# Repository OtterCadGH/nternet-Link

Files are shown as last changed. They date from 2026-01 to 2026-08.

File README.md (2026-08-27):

# nternet-Link

**An open-hardware platform that turns a TI-Nspire graphing calculator into a
networked handheld terminal.** It adds Wi-Fi, an AI chat/tutor, a camera that
reads and solves problems, and onboard storage, all through a small plug-in
device.

New to the Nspire scene? The spelling "nternet" is intentional. The Nspire's name plays on "inspire", and community projects follow suit by dropping the first letter, like the Ndless jailbreak playing on "endless". nternet is "internet", Nspire style.

Over four generations the project grew from a soldered-in modification into a
clean, reproducible, plug-in platform with a proper communication protocol and
custom PCBs.

[Discord](https://discord.gg/mB2T4Wp63e)

> **Not affiliated with or endorsed by Texas Instruments.** This is an
> embedded-systems and networking experiment. It is **not** designed or
> intended for use during exams. Follow your institution's rules.

---

## Try the calculator interface in your browser

The V4 calculator UI runs as a live simulator. The on-screen calculator and a
virtual ESP32 talk over the *real* V4 wire protocol, so you can experiment with
the whole experience before building anything.

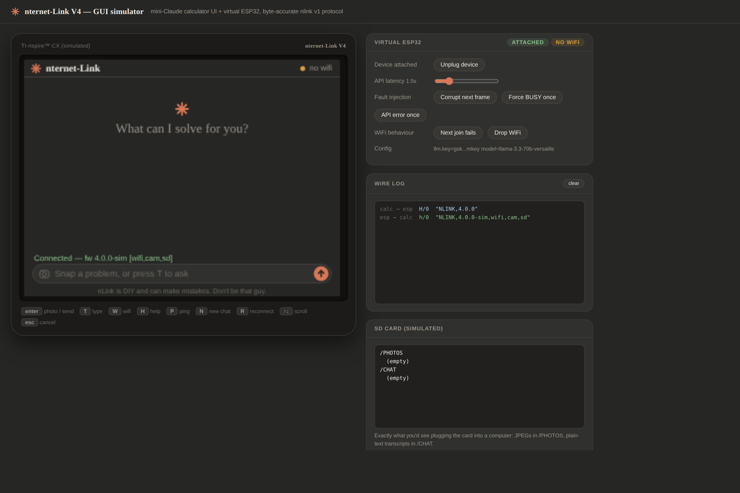
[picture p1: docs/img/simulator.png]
nternet-Link V4 GUI simulator


**[Open the live simulator](https://ottercadgh.github.io/nternet-Link/v4/tools/gui_simulator.html)**,
or download [`v4/tools/gui_simulator.html`](v4/tools/gui_simulator.html) and
open it in any browser (it runs fully offline).

---

## Which version should I look at?

**Build [V4](v4/). It is the current, recommended generation.** The others are
here as history and reference.

| | Version | What it is | Build it? |
| --- | --- | --- | --- |
| 🟢 | **[V4](v4/)** | Rewritten firmware, protocol, and UI. Two custom PCBs: a full **camera** stick and a tiny **chat-only** board. Browser simulator, automated tests. | **Yes, start here** |
| ⚪ | [V3](v3/) | First ESP32-S3 and camera platform, with a host proxy server. | Superseded |
| ⚪ | [V2](v2/) | First external USB plug-in adapter (ESP32-C3). No calculator mod. | Superseded |
| ⚪ | [V1](v1/) | The original: an ESP32 soldered *inside* the calculator. | Legacy / reference |

---

## How it works

```
 TI-Nspire  =USB=>  nternet-Link device  =Wi-Fi=>  AI provider
 (keyboard,         (ESP32 + USB bridge             (Groq / OpenAI /
  screen, Lua)       + camera + SD)                  OpenRouter / local)
```

The calculator supplies the keyboard and screen and runs a Lua app. The device
is an ESP32 that bridges USB-serial to Wi-Fi, calls an AI API, drives a camera,
and stores photos and chat logs on a microSD card. In V4 the two sides speak
**nlink v1**, a framed protocol with CRC checks and automatic retries.

---

## Repository layout

```
README.md          you are here: the project hub
docs/              shared assets (hub images)
v1/                Ti-GPT, internal mod (legacy)
   firmware/       ESP32 .ino
   calculator/     Lua app + .tns
v2/                external adapter (docs)
v3/                ESP32-S3 and camera platform
   firmware/       ESP32 .ino
   calculator/     Lua app + .tns
   server/         host proxy server
v4/                CURRENT: the full rewrite
   README.md       tutorial and build guide (start here)
   src/ include/   ESP32 firmware (C++)
   calculator/     TI-Nspire Lua client + demo
   tools/          browser GUI simulator
   docs/           protocol spec
   test/           host-side tests
   hardware/       PCB design + 4 KiCad board variants
```

Each version folder has its own README. New here? Open [`v4/`](v4/).

---

## The story

**V1 (2025)** proved the concept by soldering an ESP32 onto the calculator's
USB lines. **V2** moved all the electronics *outside* into a plug-in adapter,
with no calculator modification. **V3** jumped to the ESP32-S3 with a camera
and a host proxy. **V4** is the ground-up rewrite: a reliable checksummed
protocol, no API keys in the source (they live in the device's flash), support
for any OpenAI-compatible AI provider, a browser simulator, automated tests,
and two custom circuit boards.

## License and spirit

Open hardware and software. Modify, improve, and share. Built for learning
about USB, serial protocols, embedded networking, and hardware interfacing.

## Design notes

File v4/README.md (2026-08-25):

# nternet-Link V4

**Turn a TI-Nspire graphing calculator into a networked handheld terminal.**
It adds Wi-Fi, an AI chat/tutor, a camera that reads and solves problems, and a
microSD card, all through a tiny plug-in device. No calculator modification.

V4 is a ground-up rewrite of the firmware, the calculator software, the
communication protocol, and the hardware, with two board designs: a full
camera stick and a tiny chat-only "stealth" version.

> **Not affiliated with Texas Instruments.** This is an embedded-systems and
> networking experiment. It is **not** designed or intended for use during
> exams. Follow your school's rules. Don't be that guy.

---

## Try it first: the calculator UI runs in your browser

Before you build anything, you can play with the exact interface the
calculator runs. This simulator is the *real* thing: the on-screen
calculator and a virtual ESP32 talk to each other over the actual V4 wire
protocol, byte for byte.

nternet-Link V4 GUI simulator

### [Open the live simulator](https://ottercadgh.github.io/nternet-Link/v4/tools/gui_simulator.html)

*(That live link works once GitHub Pages is enabled. See
[Publish the demo](#publish-the-demo-optional) below. Until then, download
[`tools/gui_simulator.html`](tools/gui_simulator.html) and double-click it.
It runs fully offline in any browser.)*

### What to try in it

1. **Click the calculator screen** to give it keyboard focus.
2. Press **`W`**, pick a Wi-Fi network, type any password, press **Enter**.
   (It's simulated, so any password "connects.")
3. Press **`T`**, type a question like `derivative of x^2`, press **Enter**,
   and watch the orange spark "think," then the answer stream in.
4. Press **Enter** on its own to "take a photo." A photo card appears and a
   solved problem streams back. Check the **SD card** panel: `IMG_0001.JPG`
   just appeared, exactly as it would on the real device.
5. Now break things on purpose with the **Virtual ESP32** panel:
   - **Corrupt next frame**: watch the wire log reject a bad packet and
     recover. This is the V4 protocol's error-checking working live.
   - **Force BUSY**, **API error**, **Drop WiFi**, **Unplug device**: see
     how the UI handles each.

The **Wire log** on the right shows every message between calculator and
device, decoded. That's the whole point of V4: a reliable, checksummed link.

---

## The four generations (and where V4 fits)

| Version | What it is | Status |
| --- | --- | --- |
| V1 Ti-GPT | ESP32 soldered *inside* the calculator | Legacy / historical |
| V2 nternet-Link | External USB plug-in adapter (ESP32-C3) | Works |
| V3 | ESP32-S3 plus camera, first modular platform | Superseded by V4 |
| **V4 (this)** | Rewritten firmware, protocol, and UI, two custom PCBs | **Current** |

**What V4 fixes from V3:** a proper checksummed packet protocol (no more
garbled responses), **no API keys baked into the source** (they live in the
device's flash, set from the calculator), support for any OpenAI-compatible AI
provider, and a clean, modular codebase with automated tests.

---

## How it works (the 30-second version)

```
 TI-Nspire  =USB=>  nternet-Link device  =Wi-Fi=>  AI provider
 (keyboard,         (ESP32 + USB bridge             (Groq / OpenAI /
  screen, Lua)       + camera + SD)                  OpenRouter / local)
```

The calculator runs a Lua app (its keyboard and screen). The device is an
ESP32 that bridges USB-serial to Wi-Fi, talks to an AI API, drives a camera,
and saves photos and chats to a microSD card. They communicate over **nlink
v1**, a small framed protocol with CRC checks and automatic retries
([full spec](docs/PROTOCOL.md)).

---

## Two boards to build

| | **nlink-cam** | **nlink-lite** |
| --- | --- | --- |
| MCU | ESP32-S3-PICO-1 (SiP) | ESP32-C3-MINI-1 |
| Features | AI chat **plus camera plus microSD** | AI chat only |
| Size | about 60 x 12.5 mm stick | about 38 x 16 mm, tiny |
| Use it for | The full experience | Minimal / discreet |

Both are in [`hardware/kicad/`](hardware/kicad/) as complete, netlist-verified
KiCad projects. Two more reference designs (`nlink-proto` on the S3-MINI-1
module, `nlink-stick` bare-chip) are included as build and de-risking variants.
See [`hardware/PCB-DESIGN.md`](hardware/PCB-DESIGN.md) for the full spec and
[`hardware/kicad/CAPTURE-PLAN.md`](hardware/kicad/CAPTURE-PLAN.md) for the
board internals.

---

## Build guide

### 1. Get the hardware

Start from a dev board to try everything before committing to a custom PCB.
A **Seeed XIAO ESP32-S3 (Sense)** gives you the S3, camera, and SD in one
module. You'll also need a **CP2102/CP2102N USB-UART bridge** and a
**USB-mini plug** to reach the calculator's port. Full parts list and wiring
in [`hardware/PCB-DESIGN.md`](hardware/PCB-DESIGN.md).

### 2. Flash the firmware

The firmware uses [PlatformIO](https://platformio.org/) (free VS Code
extension). Clone this folder, open it, and build the target for your board:

```bash
pio run -e xiao-s3    -t upload    # XIAO ESP32-S3 dev board (camera + SD)
pio run -e nlink-cam  -t upload    # custom camera PCB (ESP32-S3-PICO-1)
pio run -e nlink-lite -t upload    # custom chat-only PCB (ESP32-C3-MINI-1)
```

No secrets go in the code. You'll set your Wi-Fi and AI key **from the
calculator** in the next step.

### 3. Load the calculator app

Copy the Lua app onto your calculator with the free **TI-Nspire Student
Software** (or TiLP). The client library is
[`calculator/nlink.lua`](calculator/nlink.lua) and a ready-to-run app is
[`calculator/demo_app.lua`](calculator/demo_app.lua). Build them into a
`.tns` file and send it to the calculator.

### 4. First run

1. Plug the device into the calculator, open the app.
2. Get a free AI key (for example from [Groq](https://console.groq.com/keys)).
3. On the calculator, set it once. It's saved to the device's flash:
   ```
   CFG SET llm.key   YOUR_KEY_HERE
   CFG SET llm.base  https://api.groq.com/openai/v1
   ```
4. Press **`W`** to pick your Wi-Fi and enter the password.
5. Press **`T`** to ask a question, or **Enter** to snap a photo of a
   problem. Answers save to the SD card automatically.

Everything you'll see on screen is exactly what the
[browser simulator](#try-it-first-the-calculator-ui-runs-in-your-browser)
above shows.

---

## Repository layout

```
platformio.ini        firmware build targets
include/  src/         ESP32 firmware (C++): protocol, provisioning,
                       AI client, camera, SD storage
calculator/            TI-Nspire Lua client library + demo app
tools/gui_simulator.html   the browser demo above
docs/PROTOCOL.md       nlink v1 wire-protocol spec
test/                  host-side protocol tests (run on a PC)
hardware/              PCB design docs + 4 KiCad board variants
PROJECT-STATUS.md      current status and next steps
```

---

## Publish the demo (optional)

To make the browser simulator open from a link (so people can try it without
downloading), turn on **GitHub Pages**:

1. Repo **Settings**, then **Pages**.
2. **Build and deployment**, **Source: Deploy from a branch**.
3. Pick the branch this folder lives on and **/ (root)**, then **Save**.
4. After a minute, your simulator is live at:
   `https://ottercadgh.github.io/nternet-Link/v4/tools/gui_simulator.html`

Then the **Open the live simulator** button near the top of this page just
works.

---

## Status and roadmap

See [`PROJECT-STATUS.md`](PROJECT-STATUS.md). Short version: firmware,
protocol, simulator, and all four board schematics are done and verified.
Next up is finishing the custom-PCB layouts, porting the new UI onto the
calculator, and a first hardware bring-up.

## License and spirit

Open hardware and software. Modify, improve, and share. Built for learning
about USB, serial protocols, embedded networking, and hardware interfacing.

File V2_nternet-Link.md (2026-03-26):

# nternet-Link

### Open Source Wireless Link Adapter for TI-Nspire CX & CX II Calculators

The **nternet-Link** is an open source hardware and software alternative to the TI-Navigator wireless adapter.

It allows a TI-Nspire CX or CX II calculator to communicate with an external microcontroller over the calculator USB mini port.
This implementation uses a Seeed Studio XIAO ESP32C3 to act as a serial bridge and WiFi client, enabling data transfer, network communication, and internet connectivity for the calculator.

The project began as a proof of concept serial link and evolved into a system capable of making network requests, including a demonstration application that connects the calculator to ChatGPT through a Lua interface.

Demo: https://youtube.com/shorts/zKWZ0URra5Q?si=NUPr6w3lMf3OUgO9
---
3d Files:
https://www.thingiverse.com/thing:7322781
https://www.thingiverse.com/thing:7279226

## What It Does

The device plugs into the calculator USB mini port and creates a USB serial connection.
The ESP32C3 interprets data coming from the calculator and can:

• exchange strings and files

• act as a wireless communication bridge

• connect the calculator to the internet

• send and receive API requests

• run a ChatGPT style messaging interface on the calculator

• Run any App w/ and w/o internet capabilities

• Store Data

No modification to the calculator hardware is required.

---

## Bill of Materials

Gather the following components before beginning construction:

* Seeed Studio XIAO ESP32C3
* CP2102 USB to UART bridge module
* 90° right angle slim USB Mini male connector
* 5.6 mm toggle switch (optional)
* hookup wire (28 to 32 AWG recommended)
* soldering iron and solder
* hot glue
* 3D printed enclosure (provided in /hardware)



---

## Step 1 — Prepare the CP2102



The CP2102 board must be stripped down.

Remove:
• the USB connector
• the dupont header pins

After removal, solder wires directly to the pads:

### USB Side

| Signal | Wire Color |
| --- | --- |
| VBUS | Red |
| GND | Black |
| D+ | Green |
| D− | White |

### UART Side

| Signal | Wire Color |
| --- | --- |
| 5V | Red |
| GND | Black |
| TXD | Blue |
| RXD | Yellow |

---

## Step 2 — Attach the USB Mini Connector

Solder the USB Mini connector to the USB pads of the CP2102:

Match the signals exactly:

D+ → D+
D− → D−
VBUS → VBUS
GND → GND

This connector plugs directly into the calculator.

---

## Step 3 — Connect to the ESP32C3

Wire the CP2102 UART pins to the XIAO ESP32C3:

| CP2102 | ESP32C3 |
| --- | --- |
| TXD | RX |
| RXD | TX |
| 5V | VIN |
| GND | GND |

Important:

* TX and RX are crossed (TX → RX and RX → TX)
* Grounds must be common across all devices

Optional:
You may install the toggle switch inline with the 5V line coming from the USB Mini connector to act as a power switch.



---

## Step 4 — Install Into the Case



Place the full assembly into the provided 3D printed enclosure.

Ensure:
• the USB Mini connector aligns with the opening
• the ESP32C3 USB-C port remains accessible

---

## Step 5 — Final Assembly



Insert the toggle switch into the rear sleeve.

Then secure the electronics using hot glue:

Important:
Do NOT cover the ESP32C3.
The board must be able to pivot upward so code can be uploaded over USB-C.

The enclosure is designed so the ESP32C3 can hinge outward for programming.



---
## Step 5 — Final Assembly
Insert Nternet-Link Into calculator!



Watch the Demo Here:

https://youtube.com/shorts/zKWZ0URra5Q?si=NUPr6w3lMf3OUgO9

---

## Demo Applications

### Serial Echo Demo

A simple Lua program running on the calculator sends a string to the ESP32C3.

The ESP32C3 immediately returns the same string.

This verifies:
• USB communication
• UART communication
• calculator software communication

---

### ChatGPT Demo

A second demonstration expands the concept.

The calculator Lua application:
• accepts user text input
• sends the string to the ESP32C3

The ESP32C3:
• connects to WiFi
• performs a ChatGPT API request
• returns the response

The calculator then renders a chat style interface directly on the screen.

The result is a functional conversational interface entirely running from a graphing calculator.

---

## Software

Calculator software is written in Lua using the TI-Nspire Lua API.

ESP32 firmware is written in Arduino framework for ESP32C3.

Both are provided in the `/software` directory.

---

## Open Source

All hardware, firmware, and calculator software are released open source.

You are encouraged to modify, improve, and redistribute this project.

---

## Disclaimer

This project is not affiliated with or endorsed by Texas Instruments.

Use at your own risk. Improper wiring may damage your calculator.

---
## Next Version (In Development)

A second generation of the nternet Link is already functional and currently being documented.

The new revision replaces the XIAO ESP32C3 with the **Seeed Studio XIAO ESP32S3**.
This upgrade was chosen because the ESP32S3 supports native USB and expansion boards, which significantly increases the capabilities of the device.

The ESP32S3 version can host Seeed Studio expansion modules including:

• Camera module (live image capture experiments)
• LoRa radio module
• Meshtastic compatible mesh networking communication

This opens the possibility of calculator to calculator wireless messaging over long distances without WiFi infrastructure.

The hardware is complete and operational.
Documentation is being prepared in video format showing assembly and operation.

I am currently collaborating with another developer who is leading major improvements to the software architecture while I focus on hardware design, electrical interfacing, and integration with the TI Nspire Lua environment.

The next revision will include:
• improved communication protocol
• cleaner serial handling
• easier firmware installation
• expanded Lua user interface
• support for additional peripherals

Source code and instructions for the ESP32S3 version will be released in this repository once the software layer is finalized.

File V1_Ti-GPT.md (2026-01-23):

# Ti-GPT (V1) by OtterCad

## Project Status Update

This repository documents the original Ti-GPT V1 implementation. While this project originally started as a YouTube video walkthrough, development has since taken a different direction and expanded beyond the scope of that initial video.

I am currently working on a clean V2 redesign and will be publishing it in a **new dedicated repository** once it is ready. V2 focuses on improved hardware integration, cleaner power and signal routing, and a more refined software experience.

This repository remains available as a reference for the original concept, hardware exploration, and early implementation details.

## About This Repository

**This Repository is a how-to guide associated with a YouTube video project to enable a Ti-Nspire CX (and others) with Chat-GPT utilizing an ESP32C3 and native .tns app.**

- Link to Video: LINK  
- Link for 3D printable Replacement Ti-nspire cx series slide cover: [LINK](https://www.thingiverse.com/thing:7279226)

## TI-Nspire CX Modification Guide

### Preparation and Disassembly

#### Determine Calculator Model

- There is some room for confusion here; I refer to two generations of the CX: the CX Gen 1 and CX Gen 2. Note that the CX Gen 2 is not the CX II. For more clarification, see images below.
- The first generation of the CX, including the CX and CX CAS, had issues with driver compatibility and featured a larger TiHub chip and larger battery area took up significant internal space.
- The CX CAS Gen 2, CX II, CX II CAS, CX II-T, and CX II-T CAS, is based on the newest TI chipset with a large motherboard and an integrated TiHub chip, offering minimal internal space.
- The CX Gen 2 is the best model for this project because it is based on the early chipset with the updated smaller battery and smaller TiHub chip.
- Note: The CX CAS Gen 2, CX II, CX II CAS, CX II-T, and CX II-T CAS are capable of undergoing this modification, but the extra 1.2mm of space in the CX Gen 1 is crucial for my needs.
- The CX Gen 2 can be distinguished from other variants by its white sides, full white back, smaller battery hatch, and navy blue front. The CX Gen 2 has white sides but a navy back and a larger square battery cover.
- More details on the internal discrepancies and visuals can be found in the video and photos below.




#### Open the Battery Housing

- Use a small Phillips screwdriver to remove the battery housing cover.
- Take out the panel and the battery to expose hidden safety screws.



#### Remove Hidden Screws

- With a one-millimeter flathead screwdriver, remove the safety screws hidden under the battery cover.
- Check under the top rubber feet for additional hidden screws. Ignore the lower feet, as there are no screws there.




#### Remove Torx Screws

- At the bottom of the calculator, remove the Torx T-6 screws.
- Keep all small parts in a safe place. Note that the CAS, CX II, and CX II CAS models have extra screws under the front fascia.



#### Wedge Off the Rear Housing

- Use guitar picks or similar pry tools to gently separate the rear housing from the body, working your way around the sides until the back pops off.



#### Prepare the Motherboard

- Cover the lower motherboard face with vinyl or electrical tape to prevent any interference with the piggyback.



### Micro USB Port and Wiring

#### Address Micro USB Port

- Note that Texas Instruments reversed the pinout on the CX II; the labels are upside down. Be very careful when soldering to these pins.




#### Solder and Install Piggyback, Switches, and Connector

- Refer to the provided wiring diagram to install two switches, one for grounding the ID pin to enable host mode and the other as the main power switch for the piggyback.
- Add optional a magnetic connector to facilitate easy assembly and disassembly.
- Note pinout lables are reversed for the CX II
- Note between ESP32 and CP2102 RX -> TXD, TX -> RXD in UART communication protocol but between Ti-nspire motherboard and CP2102 D+ -> D+, and D- -> D- in USB communication protocol.



#### Adjust Internal Space

- Use necessary tools to free up internal space as needed of the calculator to accommodate the piggyback and switches.
- Optionally add USB access to the ESP for debugging purposes while it's still in the case. Heres an example of mine.

### Software Installation and Configuration

#### Download and Install Software

- Download the TI-nspire CAS student software free trial and install it.
- Use this software to upload the .tns file from the provided GitHub link to your calculator.

https://education.ti.com/fr/software/details/en/B4F6E4EE05B94D75AAB4DFE24B2720AE/ti-nspirecxcas_pc_trial

#### Setup API and Arduino

- Follow the guide by Anders Jensen to create your ChatGPT API secret key. (GUIDE LINK)
- Download and install the Arduino IDE and the necessary drivers for your ESP model.
- Edit the .INO file from this repository to include your API secret key and Hotspot or Wi-Fi details.
- Note for iphones enable Maximise Compatibility to allow your esp to connect in hotspot settings.



### Final Assembly and Testing

#### Assemble and Check Clearances

- Once all components are installed, close up the calculator by pressing firmly on the sides.
- Ensure there is enough clearance for all components.

#### Power Up and Configure

- Boot up the calculator, go to the Home Screen, enable Host mode via the first switch, and then power the piggyback bia the second switch.

#### Open and Run Ti-GPT File

- Open the Ti-GPT file in the calculator's document folder.
- Ensure the ESP has successfully connected to your hotspot.

#### Testing and Usage

- Type into the textbox and hit enter.
- For short responses, they should appear immediately.
- For longer responses, you may need to hit enter again after a few seconds.

#### Troubleshooting

- If you encounter errors, hit CTRL + W to quit the program.
- Try power cycling your piggyback and checking your wiring for any issues.
- ALWAYS disconnect power and host/ID pin when not in use.
- Esp can get pretty hot in there under load or if on/idle too long.
- Please watch the step by step on Youtube and leave a comment if you are facing issues and I will do my best to respond.

### Disclaimer

I want to make it clear that this project is created for educational purposes and technological demonstration only. I do not condone academic dishonesty or the use of this project for cheating in any form.

The tools and methods demonstrated in this project should be used responsibly and ethically. Misuse of this technology for bypassing academic regulations or dishonest practices is strictly against the principles this project upholds.

Additionally, I do not endorse or support the use of my project by others for financial gain by others. This project is open-sourced to foster innovation and learning within the community, not for commercial exploitation.

Any reproduction or use of the project's content for profit without explicit permission is strictly prohibited. Please respect the spirit of collaboration and learning that this project is built upon.

### Refrences

- ChromaLock YouTube, GitHub  
  https://www.youtube.com/@ChromaLock

- ProfessorBoots YouTube, GitHub  
  https://github.com/ProfBoots/ChatGPT-On-Arduino

- CVSoft Cemetech, GitHub  
  https://github.com/CVSoft/nspire-usb-uart-shenanigans

- AndersJensen YouTube  
  https://www.youtube.com/watch?v=OB99E7Y1cMA&ab_channel=AndersJensen

- ti-nspire YouTube  
  https://www.youtube.com/@ti-nspire301

- CSab6482 Reddit  
  https://www.reddit.com/r/UsbCHardware/comments/y2dbkf/tinspire_cx_ii_cas_usbc_mod_v2/

### Thank You

Thank you so much for engaging with my project. While this repository captures the original implementation, the project is actively evolving and V2 will be released in a separate repository with a cleaner and more refined approach.

I appreciate all the feedback, curiosity, and experimentation this project has generated. Thank you for being part of it.

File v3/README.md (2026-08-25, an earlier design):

> **nternet-Link · Version 3** — [← All versions](../README.md) · [V1](../v1/) · [V2](../v2/) · [V4](../v4/)
>
> First ESP32-S3 + camera platform. Superseded by V4 (rewritten protocol, firmware, and hardware). Code here includes the calculator app, ESP32 firmware, and a host `server/` proxy.

---

# nternet-Link V3

### Development Preview

nternet-Link V3 is the current generation of the project and remains under active development.

This version moves beyond a simple wireless adapter and turns the TI-Nspire calculator into a modular embedded terminal capable of interacting with external hardware and modern network services.

The system now uses the **Seeed Studio XIAO ESP32S3** platform and supports expansion peripherals instead of a fixed configuration.

---

## Development Update

The V3 demo programs have now been uploaded in the `/v3` folder of this repository.

These demos show working communication between the calculator Lua interface and the ESP32S3 hardware.
A full demonstration video showing the hardware, installation process, and real usage is currently being recorded and will be added to the repository soon.

---

## What It Enables

Working demonstrators currently include:

• calculator text interface to network services
• API communication through the ESP32S3
• image capture experiments
• long range wireless messaging experiments

The calculator provides the display and input while the ESP32S3 handles communication, processing, and peripherals.

---

## Expansion Direction

The platform is being designed to support attachable modules such as:

• camera input hardware
• LoRa radio communication
• Meshtastic style messaging networks

This allows calculator to calculator communication and off grid messaging without WiFi infrastructure, as well as interaction with remote services.

---

## Project Status

The hardware platform is operational and multiple prototypes are working.

I am currently collaborating with another developer who is focusing on the software architecture and communication protocol while I continue hardware integration and Lua interface development.

Current goals before full release:

• stabilize the firmware
• simplify installation
• improve reliability
• document operation clearly

Once the system is polished and reproducible, full documentation and source release will be published here along with a complete build and demonstration video.

---

## Purpose

This project explores extending legacy educational hardware using modern embedded systems and networking.

The calculator acts as a portable human interface while the external device provides connectivity and processing.

---

## Academic Use

This project is provided for learning and experimentation only and is not intended for use in examinations or to bypass institutional policies. Users are responsible for following the rules of their school or testing environment.

---

## Disclaimer

This project is not affiliated with or endorsed by Texas Instruments.

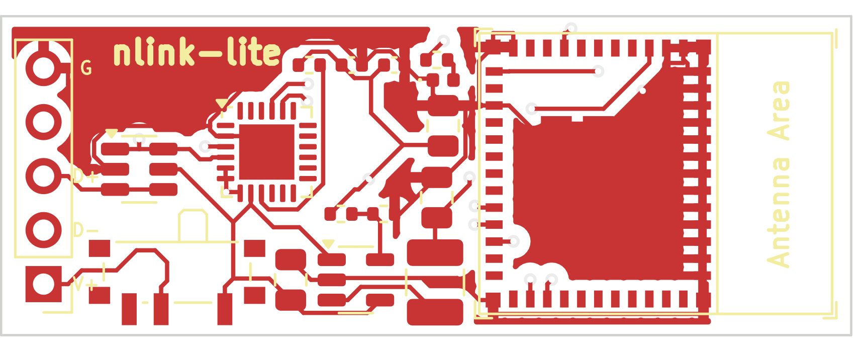
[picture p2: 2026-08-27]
v4/hardware/kicad/nlink-lite/lite_front.png

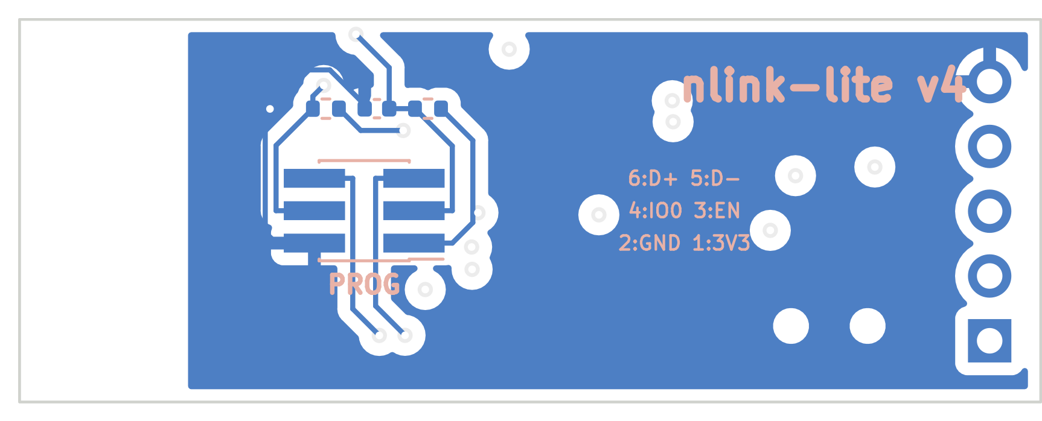
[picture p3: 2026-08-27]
v4/hardware/kicad/nlink-lite/lite_back.png

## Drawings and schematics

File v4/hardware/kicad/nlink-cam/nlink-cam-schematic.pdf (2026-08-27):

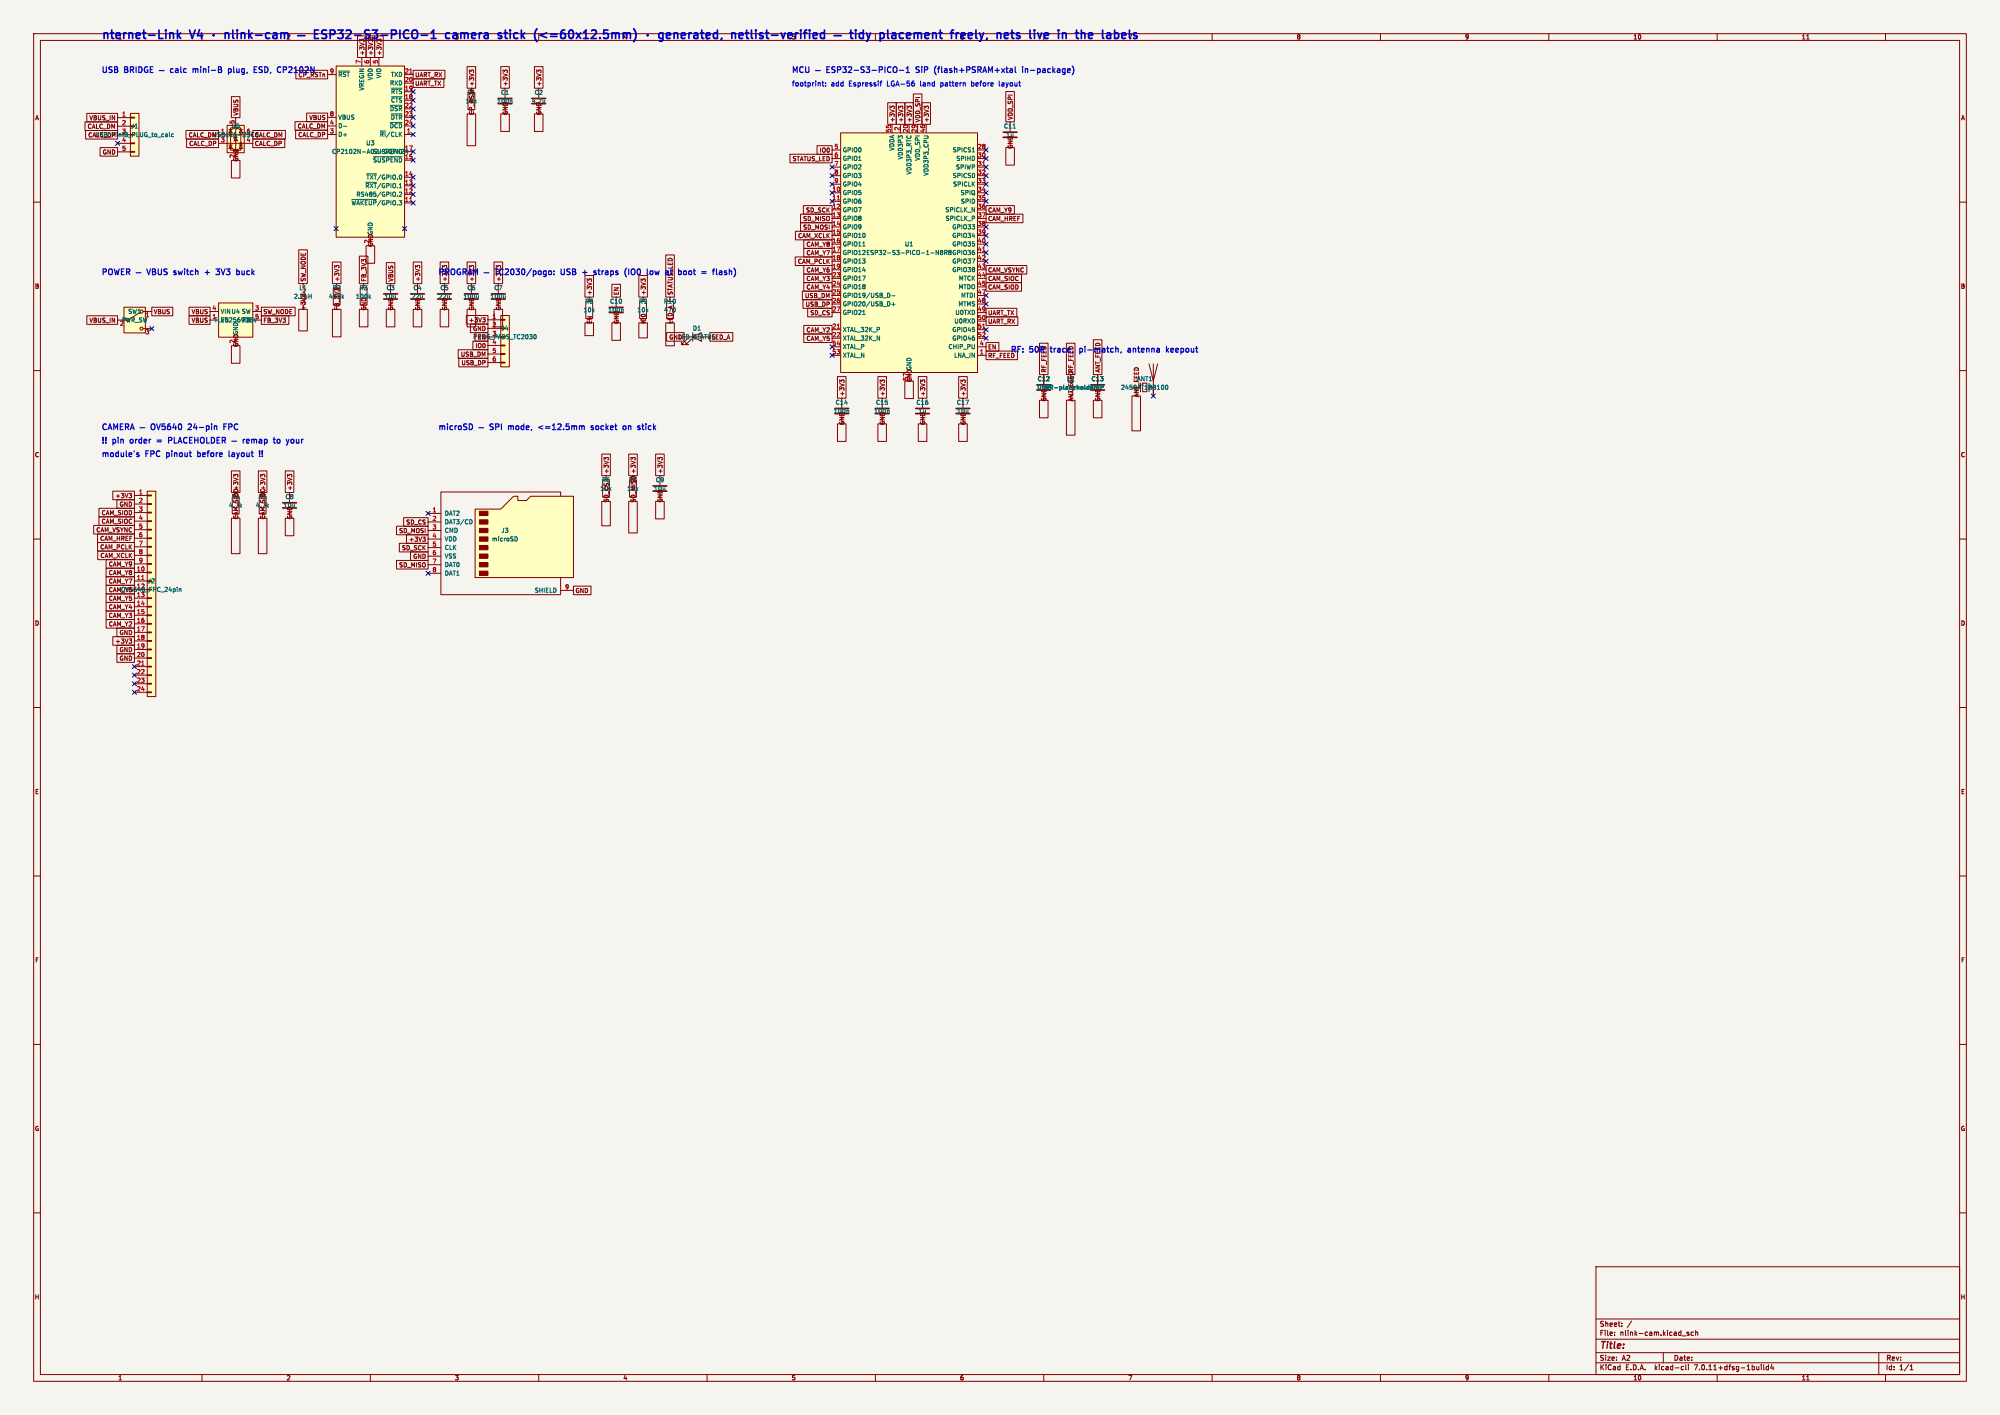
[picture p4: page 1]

2 RXD 20 TXD 21 ~{DSR} 22 ~{DTR} 23 ~{DCD} 24 D+ 3 D- 4 VIO

2 VDD3P3_RTC 20 XTAL_32K_P 21 XTAL_32K_N 22 GPIO17 23 GPIO18 24 GPIO19/USB_D- 25 GPIO20/USB_D+ 26 GPIO21 27 SPICS1 28 VDD_SPI 29 SPIHD 30 SPIWP 31 SPICS0 32 SPICLK 33 SPIQ 34 SPID 35 SPICLK_P 37 GPIO33 38 GPIO34 39 CHIP_PU 4 GPIO35 40 GPIO36 41 GPIO37 42 GPIO38 43 MTCK 44 VDD3P3_CPU 46 MTDI 47 MTMS 48 U0TXD 49 GPIO0 5 U0RXD 50 GPIO46 52 XTAL_N 53 XTAL_P 54 VDDA 55 GND 57 GPIO1 6 GPIO2 7 GPIO3 8 GPIO4 9 U1 ESP32-S3-PICO-1-N8R8 ANT1
UART_TX UART_RX CAM_HREF CAM_VSYNC

POWER þÿ VBUS switch + 3V3 buck

!! pin order = PLACEHOLDER þÿ remap to your
module's FPC pinout before layout !!

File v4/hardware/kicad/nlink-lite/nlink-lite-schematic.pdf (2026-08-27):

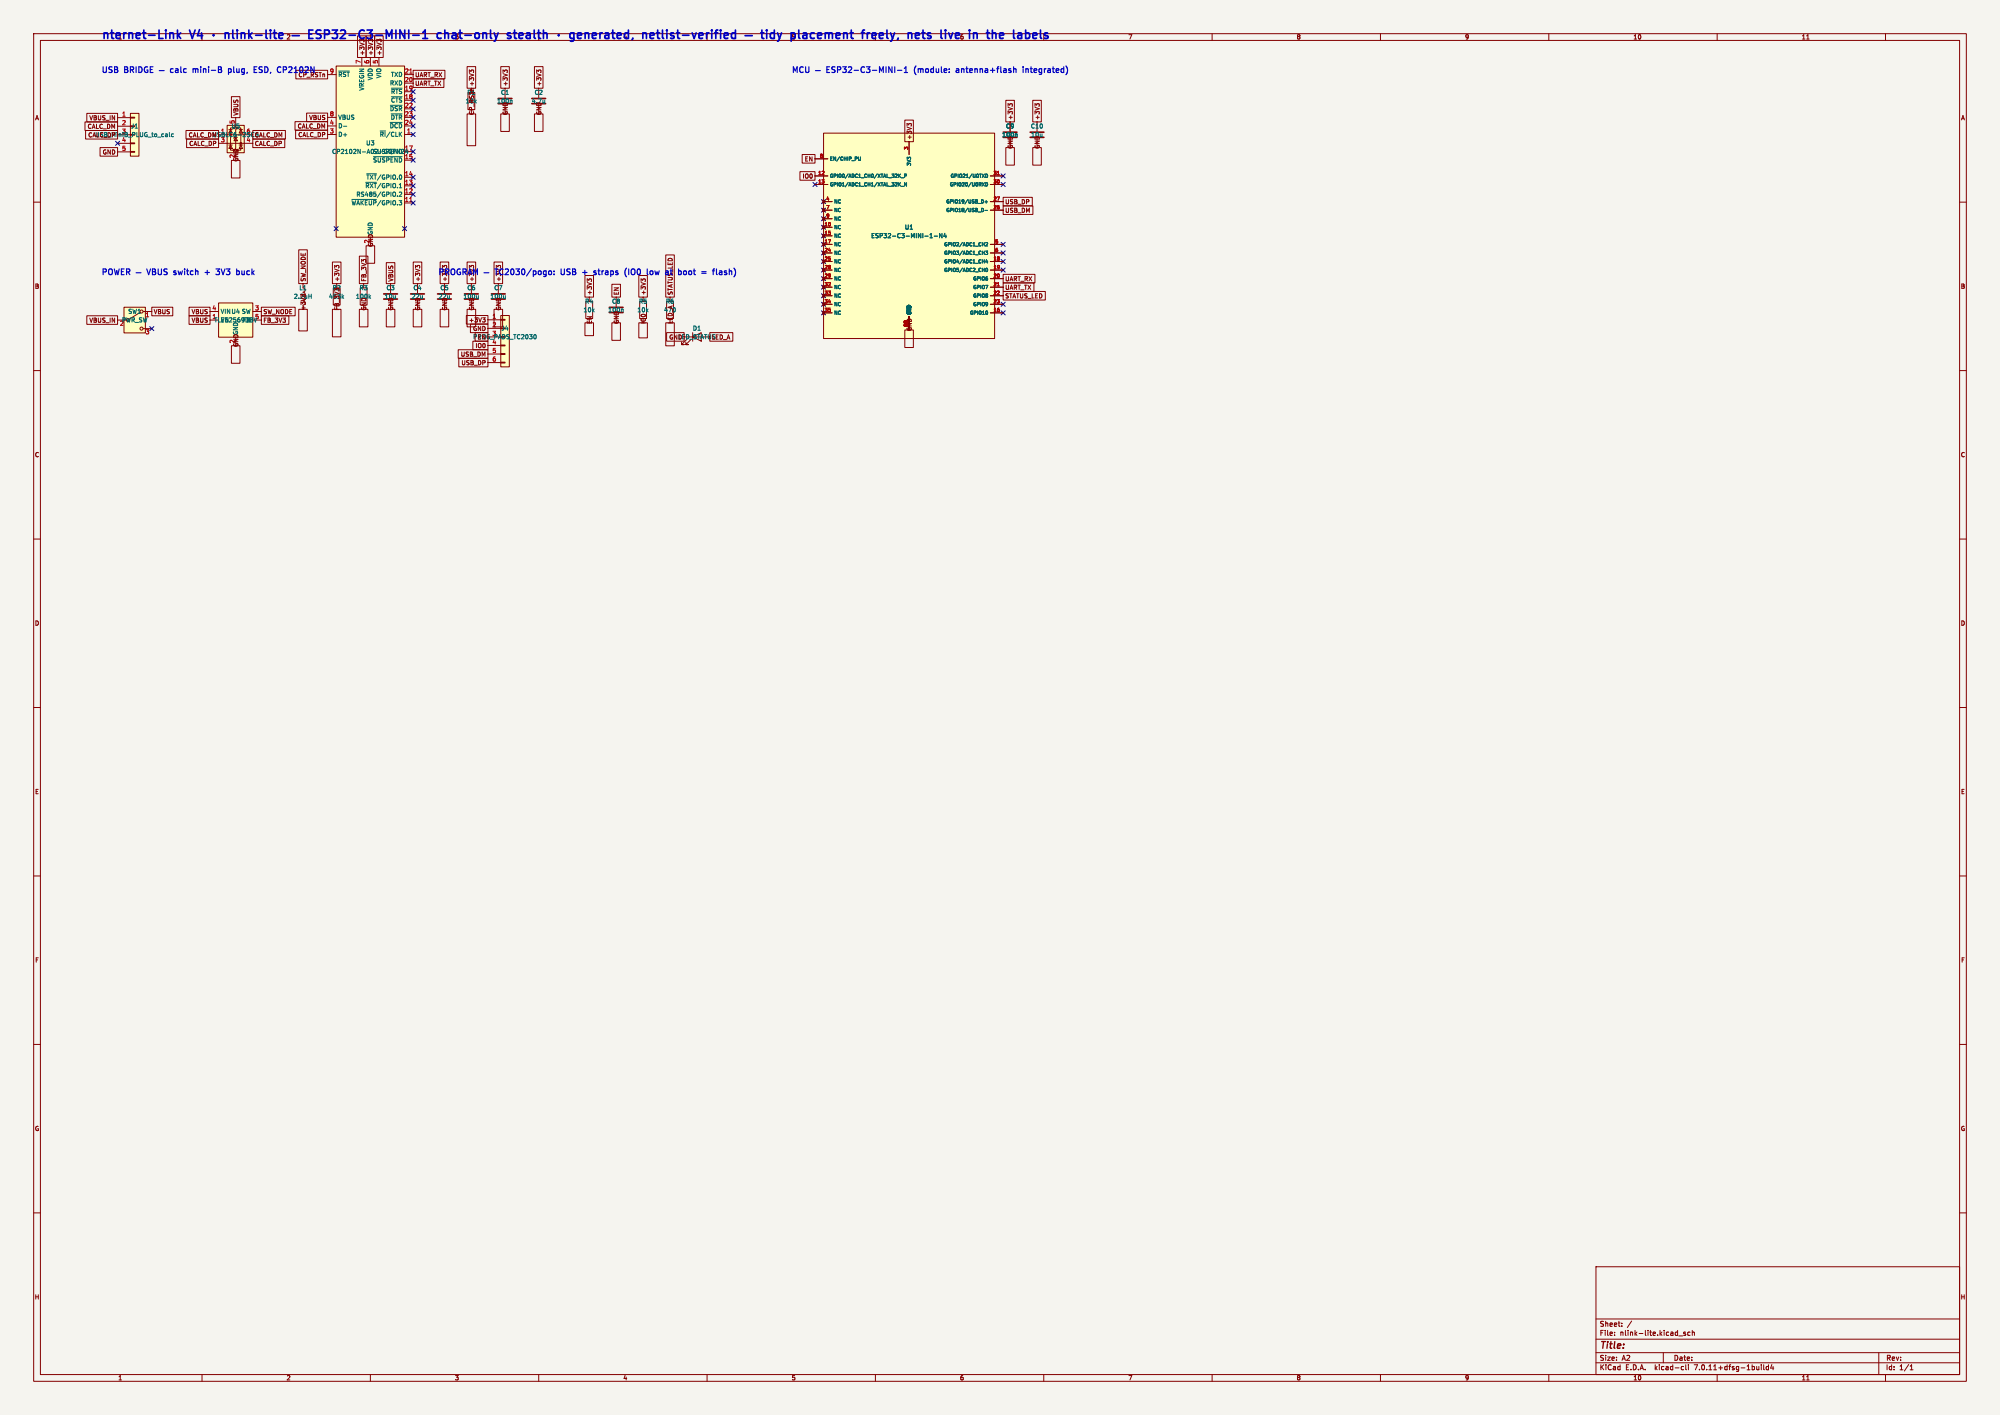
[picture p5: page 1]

2 RXD 20 TXD 21 ~{DSR} 22 ~{DTR} 23 ~{DCD} 24 D+ 3 D- 4 VIO

3 GPIO20/U0RXD 30 GPIO21/U0TXD 31 NC 32 NC 33 NC 34 NC 35 GND 36789 NC 4 401234564789 GPIO2/ADC1_CH2 5 50123 GPIO3/ADC1_CH3 6 NC 7 EN/CHIP_PU 8 NC 9 C9

3 GPIO20/U0RXD 30 GPIO21/U0TXD 31 NC 32 NC 33 NC 34 NC 35 GND 36789 NC 4 401234564789 GPIO2/ADC1_CH2 5 50123 GPIO3/ADC1_CH3 6 NC 7 EN/CHIP_PU 8 NC 9 U1 ESP32-C3-MINI-1-N4 FB_3V3 +3V3

2 GPIO6 20 GPIO7 21 GPIO8 22 GPIO9 23 NC 24 NC 25 GPIO18/USB_D- 26 GPIO19/USB_D+ 27 NC 28 NC 29 3V3

1 NC 10 11 GPIO0/ADC1_CH0/XTAL_32K_P 12 GPIO1/ADC1_CH1/XTAL_32K_N 13 GND 14 NC 15 GPIO10 16 NC 17 GPIO4/ADC1_CH4 18 GPIO5/ADC2_CH0 19 GND

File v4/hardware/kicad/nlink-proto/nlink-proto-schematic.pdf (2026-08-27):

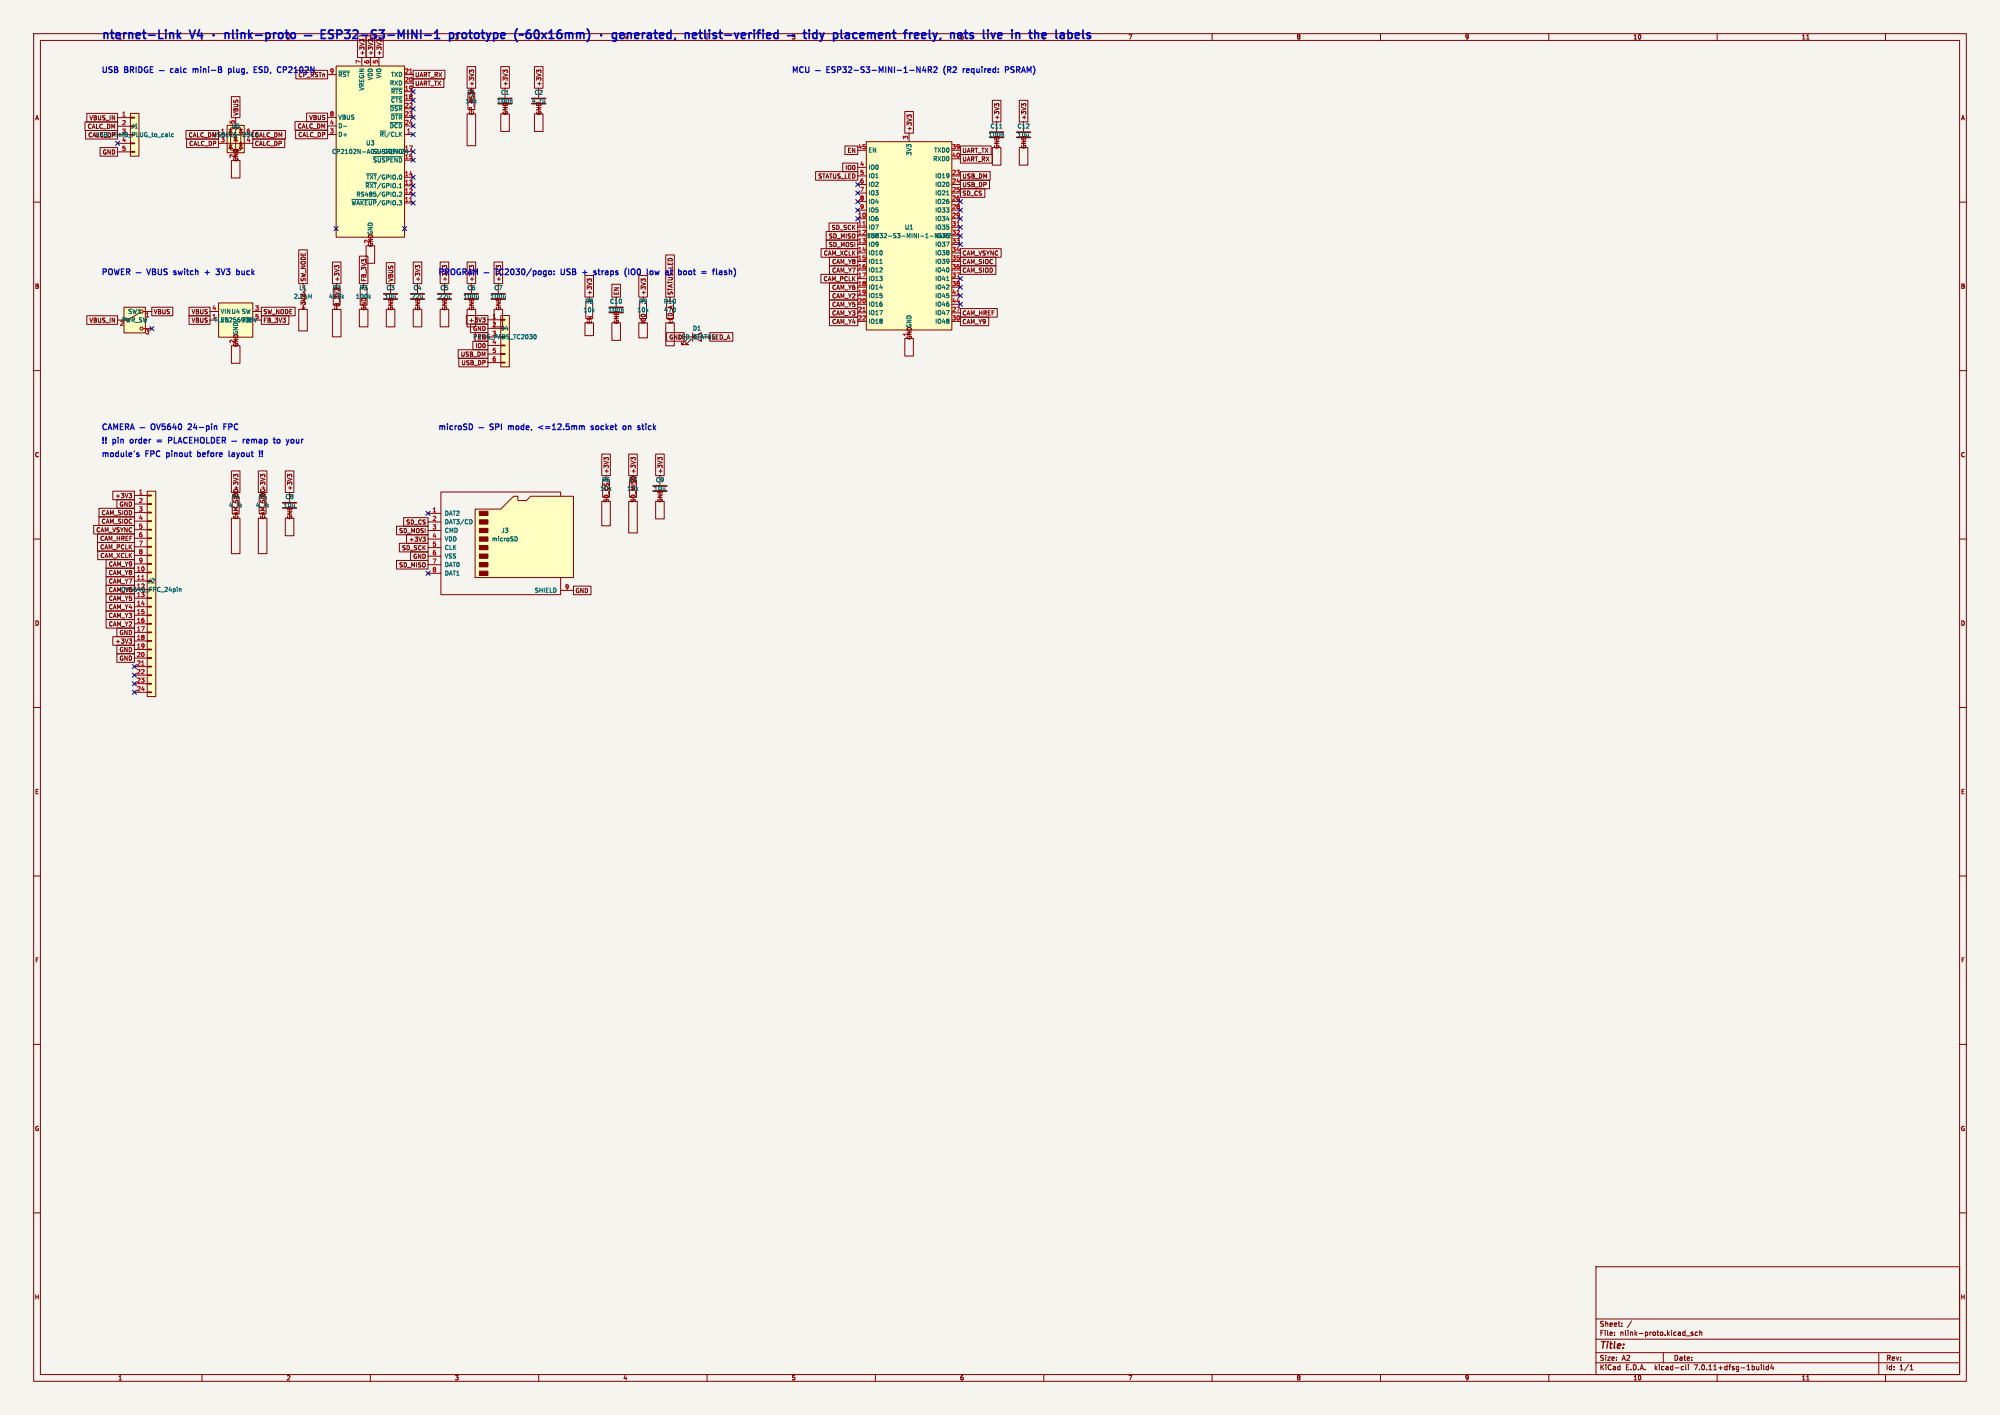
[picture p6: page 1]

2 RXD 20 TXD 21 ~{DSR} 22 ~{DTR} 23 ~{DCD} 24 D+ 3 D- 4 VIO

POWER þÿ VBUS switch + 3V3 buck

2 SW 3 VIN 4 FB 5 U4 TLV62569DBV DAT2 1 DAT3/CD 2 CMD 3 VDD 4 CLK 5 VSS 6 DAT0 7 DAT1 8 SHIELD 9

!! pin order = PLACEHOLDER þÿ remap to your

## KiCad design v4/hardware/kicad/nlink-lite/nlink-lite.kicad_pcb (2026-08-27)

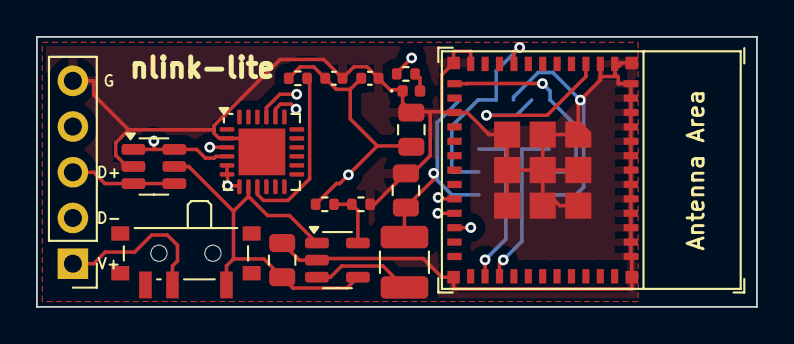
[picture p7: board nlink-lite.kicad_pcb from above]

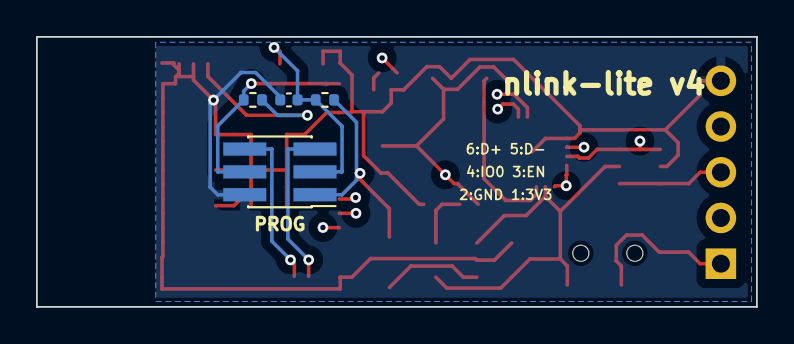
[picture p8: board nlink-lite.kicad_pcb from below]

Board: 4 copper layers, 40.0 x 15.0 mm, 21 parts (4 on the bottom side), 17 nets.

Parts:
C1, C6: 100n; C_0402_1005Metric
C2: 4.7u; C_0402_1005Metric
C3, C5: 10u; C_0805_2012Metric
C4: 22u; C_0805_2012Metric
D1: LED_STATUS; LED_0402_1005Metric
J1: USB_MiniB_PLUG_to_calc; PinHeader_1x05_P2.54mm_Vertical
J4: PROG_PADS_2x3_POGO; PinHeader_2x03_P1.27mm_Vertical_SMD
L1: 2.2uH; L_1210_3225Metric
R1, R4, R5: 10k; R_0402_1005Metric
R2: 453k; R_0402_1005Metric
R3: 100k; R_0402_1005Metric
R6: 470; R_0402_1005Metric
SW1: PWR_SW; SW_SPDT_PCM12
U1: ESP32-C3-MINI-1-N4; ESP32-C3-MINI-1
U3: CP2102N-A02-GQFN24; QFN-24-1EP_4x4mm_P0.5mm_EP2.6x2.6mm
U4: TLV62569DBV; SOT-23-5
U5: USBLC6-2SC6; SOT-23-6

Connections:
+3V3: C1.1, C2.1, C4.1, C5.1, J4.1, L1.2, R1.1, R2.1, R4.1, R5.1, U1.3, U3.5, U3.6, U3.7
CALC_DM: J1.2, U3.4, U5.1, U5.6
CALC_DP: J1.3, U3.3, U5.3, U5.4
CP_RSTn: R1.2, U3.9
EN: C6.1, J4.3, R4.2, U1.8
FB_3V3: R2.2, R3.1, U4.5
GND: C1.2, C2.2, C3.2, C4.2, C5.2, C6.2, D1.1, J1.5, J4.2, R3.2, U1.1, U1.2, U1.11, U1.14, U1.36, U1.37, U1.38, U1.39, U1.40, U1.41, U1.42, U1.43, U1.44, U1.45, U1.46, U1.47, U1.48, U1.49, U1.50, U1.51, U1.52, U1.53, U3.2, U3.25, U4.2, U5.2
IO0: J4.4, R5.2, U1.12
LED_A: D1.2, R6.2
STATUS_LED: R6.1, U1.22
SW_NODE: L1.1, U4.3
UART_RX: U1.20, U3.21
UART_TX: U1.21, U3.20
USB_DM: J4.5, U1.26
USB_DP: J4.6, U1.27
VBUS: C3.1, SW1.1, U3.8, U4.1, U4.4, U5.5
VBUS_IN: J1.1, SW1.2

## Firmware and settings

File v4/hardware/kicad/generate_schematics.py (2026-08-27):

#!/usr/bin/env python3
"""Generate nlink-proto and nlink-stick KiCad schematics + board stubs.

Reads official KiCad 7 symbol libraries, places symbols in a utilitarian grid,
and attaches global labels at exact pin coordinates (label-everything style —
connectivity lives in the labels, no drawn wires). Verified afterwards by
exporting the netlist with kicad-cli and asserting the nets from
CAPTURE-PLAN.md — see verify_netlists.py.

Regenerate: python3 generate_schematics.py
"""
import re, uuid, os, json

OUT = os.path.dirname(os.path.abspath(__file__))
# Stock KiCad symbols + the project's vendored Espressif library (C3-MINI-1).
LIBDIRS = ["/usr/share/kicad/symbols", os.path.join(OUT, "lib")]

# ---------------------------------------------------------------------------
# symbol library access
# ---------------------------------------------------------------------------
def extract_symbol_text(lib, name):
    """Return the raw s-expr text of (symbol "name" ...) from a library."""
    text = None
    for d in LIBDIRS:
        p = f"{d}/{lib}.kicad_sym"
        if os.path.exists(p) and f'(symbol "{name}"' in open(p).read():
            text = open(p).read()
            break
    if text is None:
        raise FileNotFoundError(f"symbol {lib}:{name} not found in {LIBDIRS}")
    marker = f'(symbol "{name}"'
    start = text.index(marker)
    depth = 0
    for i in range(start, len(text)):
        if text[i] == '(':
            depth += 1
        elif text[i] == ')':
            depth -= 1
            if depth == 0:
                return text[start:i + 1]
    raise ValueError(name)

def parse_pins(sym_text):
    """[(number, name, x, y, angle)] from a symbol's raw text."""
    pins = []
    for m in re.finditer(
        r'\(pin\s+\S+\s+\S+\s*\(at\s+([-\d.]+)\s+([-\d.]+)\s+([-\d.]+)\)'
        r'.*?\(name\s+"([^"]*)".*?\(number\s+"([^"]*)"', sym_text, re.S):
        x, y, ang, name, num = m.groups()
        pins.append((num, name, float(x), float(y), float(ang)))
    return pins

def U(): return str(uuid.uuid4())
def fmt(v): return f"{round(v + 0.0, 2):g}"

# ---------------------------------------------------------------------------
# schematic writer
# ---------------------------------------------------------------------------
class Schematic:
    def __init__(self, project):
        self.project = project
        self.root_uuid = U()
        self.libparts = {}     # "Lib:Name" -> embedded text
        self.body = []

    def use_symbol(self, lib, name):
        key = f"{lib}:{name}"
        if key not in self.libparts:
            raw = extract_symbol_text(lib, name)
            raw = raw.replace(f'(symbol "{name}"', f'(symbol "{key}"', 1)
            self.libparts[key] = raw
        return key

    def place(self, ref, lib, name, value, footprint, at, nets, extra_props=None):
        """Place symbol at `at`; nets maps pin_number -> net label (None=NC)."""
        key = self.use_symbol(lib, name)
        pins = parse_pins(self.libparts[key])
        sx, sy = at
        su = U()
        p = [f'  (symbol (lib_id "{key}") (at {fmt(sx)} {fmt(sy)} 0) (unit 1)',
             f'    (in_bom yes) (on_board yes) (dnp no) (uuid {su})',
             f'    (property "Reference" "{ref}" (at {fmt(sx)} {fmt(sy - 2.54)} 0)',
             f'      (effects (font (size 1.27 1.27))))',
             f'    (property "Value" "{value}" (at {fmt(sx)} {fmt(sy)} 0)',
             f'      (effects (font (size 1.27 1.27))))',
             f'    (property "Footprint" "{footprint}" (at {fmt(sx)} {fmt(sy)} 0)',
             f'      (effects (font (size 1.27 1.27)) hide))',
             f'    (property "Datasheet" "" (at {fmt(sx)} {fmt(sy)} 0)',
             f'      (effects (font (size 1.27 1.27)) hide))']
        for k, v in (extra_props or {}).items():
            p.append(f'    (property "{k}" "{v}" (at {fmt(sx)} {fmt(sy)} 0)'
                     f' (effects (font (size 1.27 1.27)) hide))')
        for num, _, _, _, _ in pins:
            p.append(f'    (pin "{num}" (uuid {U()}))')
        p.append(f'    (instances (project "{self.project}"'
                 f' (path "/{self.root_uuid}" (reference "{ref}") (unit 1))))')
        p.append('  )')
        self.body.append("\n".join(p))

        # labels / no-connects at pin endpoints, grouped by position
        by_pos = {}
        for num, pname, px, py, pang in pins:
            pos = (round(sx + px, 2), round(sy - py, 2))
            by_pos.setdefault(pos, []).append((num, pname, pang))
        for (x, y), plist in by_pos.items():
            netnames = {nets.get(num) for num, _, _ in plist if nets.get(num)}
            assert len(netnames) <= 1, f"{ref}: conflicting nets at {(x,y)}: {netnames}"
            if netnames:
                net = netnames.pop()
                ang = plist[0][2]
                lang = {0: 180, 180: 0, 90: 270, 270: 90}.get(ang, 0)
                just = "right" if lang == 180 else "left"
                self.body.append(
                    f'  (global_label "{net}" (shape passive)'
                    f' (at {fmt(x)} {fmt(y)} {lang})'
                    f' (effects (font (size 1.27 1.27)) (justify {just}))'
                    f' (uuid {U()}))')
            else:
                self.body.append(f'  (no_connect (at {fmt(x)} {fmt(y)}) (uuid {U()}))')

    def text(self, s, at, size=2.0):
        x, y = at
        s = s.replace('"', "'")
        self.body.append(
            f'  (text "{s}" (at {fmt(x)} {fmt(y)} 0)'
            f' (effects (font (size {size} {size}) bold) (justify left bottom))'
            f' (uuid {U()}))')

    def write(self, path):
        out = ['(kicad_sch (version 20230121) (generator nlink_gen)', '',
               f'  (uuid {self.root_uuid})', '', '  (paper "A2")', '',
               '  (lib_symbols']
        for raw in self.libparts.values():
            out.append("    " + raw.replace("\n", "\n    "))
        out.append('  )')
        out.append('')
        out.extend(self.body)
        out.append('')
        out.append(f'  (sheet_instances (path "/" (page "1")))')
        out.append(')')
        open(path, "w").write("\n".join(out) + "\n")

# ---------------------------------------------------------------------------
# passive helper
# ---------------------------------------------------------------------------
class Ctx:
    def __init__(self, sch):
        self.sch = sch
        self.n = {"R": 0, "C": 0, "L": 0}
    def rcl(self, kind, value, at, net1, net2, fp=None):
        self.n[kind] += 1
        ref = f"{kind}{self.n[kind]}"
        fp = fp or {"R": "Resistor_SMD:R_0402_1005Metric",
                    "C": "Capacitor_SMD:C_0402_1005Metric",
                    "L": "Inductor_SMD:L_1210_3225Metric"}[kind]
        self.sch.place(ref, "Device", kind, value, fp, at, {"1": net1, "2": net2})
        return ref

# ---------------------------------------------------------------------------
# shared circuitry (both variants)
# ---------------------------------------------------------------------------
def add_shared(sch, ctx):
    # --- calculator plug + ESD + bridge --------------------------------------
    sch.text("USB BRIDGE — calc mini-B plug, ESD, CP2102N", (30, 22), 1.7)
    sch.place("J1", "Connector_Generic", "Conn_01x05", "USB_MiniB_PLUG_to_calc",
              "", (40, 40),
              {"1": "VBUS_IN", "2": "CALC_DM", "3": "CALC_DP", "5": "GND"},
              {"MPN": "mini-B male plug — see PCB-DESIGN.md options"})
    sch.place("U5", "Power_Protection", "USBLC6-2P6", "USBLC6-2SC6",
              "Package_TO_SOT_SMD:SOT-23-6", (70, 40),
              {"1": "CALC_DM", "6": "CALC_DM", "3": "CALC_DP", "4": "CALC_DP",
               "5": "VBUS", "2": "GND"})
    sch.place("U3", "Interface_USB", "CP2102N-Axx-xQFN24", "CP2102N-A02-GQFN24",
              "Package_DFN_QFN:QFN-24-1EP_4x4mm_P0.5mm_EP2.6x2.6mm", (110, 45),
              {"3": "CALC_DP", "4": "CALC_DM", "8": "VBUS",
               "5": "+3V3", "6": "+3V3", "7": "+3V3",
               "9": "CP_RSTn", "20": "UART_TX", "21": "UART_RX",
               "2": "GND", "25": "GND"})
    ctx.rcl("R", "10k", (140, 30), "+3V3", "CP_RSTn")
    ctx.rcl("C", "100n", (150, 30), "+3V3", "GND")
    ctx.rcl("C", "4.7u", (160, 30), "+3V3", "GND")

    # --- power ---------------------------------------------------------------
    sch.text("POWER — VBUS switch + 3V3 buck", (30, 82), 1.7)
    sch.place("SW1", "Switch", "SW_SPDT", "PWR_SW", "", (40, 95),
              {"2": "VBUS_IN", "1": "VBUS"})
    sch.place("U4", "Regulator_Switching", "TLV62568DBV", "TLV62569DBV",
              "Package_TO_SOT_SMD:SOT-23-5", (70, 95),
              {"4": "VBUS", "1": "VBUS", "2": "GND", "3": "SW_NODE", "5": "FB_3V3"})
    ctx.rcl("L", "2.2uH", (90, 88), "SW_NODE", "+3V3")
    ctx.rcl("R", "453k", (100, 88), "+3V3", "FB_3V3")
    ctx.rcl("R", "100k", (108, 88), "FB_3V3", "GND")
    ctx.rcl("C", "10u", (116, 88), "VBUS", "GND",
            fp="Capacitor_SMD:C_0805_2012Metric")
    ctx.rcl("C", "22u", (124, 88), "+3V3", "GND",
            fp="Capacitor_SMD:C_0805_2012Metric")
    ctx.rcl("C", "22u", (132, 88), "+3V3", "GND",
            fp="Capacitor_SMD:C_0805_2012Metric")
    ctx.rcl("C", "100u", (140, 88), "+3V3", "GND",
            fp="Capacitor_SMD:C_1210_3225Metric")
    ctx.rcl("C", "100u", (148, 88), "+3V3", "GND",
            fp="Capacitor_SMD:C_1210_3225Metric")

def add_camera_sd(sch, ctx):
    # --- camera --------------------------------------------------------------
    sch.text("CAMERA — OV5640 24-pin FPC", (30, 128), 1.7)
    sch.text("!! pin order = PLACEHOLDER — remap to your", (30, 132), 1.7)
    sch.text("module's FPC pinout before layout !!", (30, 136), 1.7)
    cam = {"1": "+3V3", "2": "GND", "3": "CAM_SIOD", "4": "CAM_SIOC",
           "5": "CAM_VSYNC", "6": "CAM_HREF", "7": "CAM_PCLK", "8": "CAM_XCLK",
           "9": "CAM_Y9", "10": "CAM_Y8", "11": "CAM_Y7", "12": "CAM_Y6",
           "13": "CAM_Y5", "14": "CAM_Y4", "15": "CAM_Y3", "16": "CAM_Y2",
           "17": "GND", "18": "+3V3", "19": "GND", "20": "GND"}
    sch.place("J2", "Connector_Generic", "Conn_01x24", "OV5640_FPC_24pin",
              "Connector_FFC-FPC:Hirose_FH12-24S-0.5SH_1x24-1MP_P0.50mm_Horizontal",
              (45, 175), cam)
    ctx.rcl("R", "4.7k", (70, 150), "+3V3", "CAM_SIOD")
    ctx.rcl("R", "4.7k", (78, 150), "+3V3", "CAM_SIOC")
    ctx.rcl("C", "10u", (86, 150), "+3V3", "GND",
            fp="Capacitor_SMD:C_0805_2012Metric")

    # --- microSD -------------------------------------------------------------
    sch.text("microSD — SPI mode, <=12.5mm socket on stick", (130, 128), 1.7)
    sch.place("J3", "Connector", "Micro_SD_Card", "microSD",
              "Connector_Card:microSD_HC_Hirose_DM3AT-SF-PEJM5", (150, 160),
              {"2": "SD_CS", "3": "SD_MOSI", "4": "+3V3", "5": "SD_SCK",
               "6": "GND", "7": "SD_MISO", "9": "GND"})
    ctx.rcl("R", "10k", (180, 145), "+3V3", "SD_CS")
    ctx.rcl("R", "10k", (188, 145), "+3V3", "SD_MISO")
    ctx.rcl("C", "10u", (196, 145), "+3V3", "GND",
            fp="Capacitor_SMD:C_0805_2012Metric")

def add_program(sch, ctx, j4_fp="Connector:Tag-Connect_TC2030-IDC-FP_2x03_P1.27mm_Vertical"):
    # --- programming pads + straps + LED -------------------------------------
    sch.text("PROGRAM — TC2030/pogo: USB + straps (IO0 low at boot = flash)", (130, 82), 1.7)
    sch.place("J4", "Connector_Generic", "Conn_01x06", "PROG_PADS_TC2030",
              j4_fp,
              (150, 100),
              {"1": "+3V3", "2": "GND", "3": "EN", "4": "IO0",
               "5": "USB_DM", "6": "USB_DP"})
    ctx.rcl("R", "10k", (175, 92), "+3V3", "EN")
    ctx.rcl("C", "100n", (183, 92), "EN", "GND")
    ctx.rcl("R", "10k", (191, 92), "+3V3", "IO0")
    ctx.rcl("R", "470", (199, 92), "STATUS_LED", "LED_A")
    sch.place("D1", "Device", "LED", "LED_STATUS",
              "LED_SMD:LED_0402_1005Metric", (207, 100),
              {"2": "LED_A", "1": "GND"})

# ---------------------------------------------------------------------------
# variant MCU sections
# ---------------------------------------------------------------------------
def add_mcu_mini(sch, ctx):
    sch.text("MCU — ESP32-S3-MINI-1-N4R2 (R2 required: PSRAM)", (235, 22), 1.7)
    sch.place("U1", "MCU_Espressif", "ESP32-S3-MINI-1", "ESP32-S3-MINI-1-N4R2",
              "RF_Module:ESP32-S3-MINI-1", (270, 70),
              {"3": "+3V3", "45": "EN", "4": "IO0", "5": "STATUS_LED",
               "39": "UART_TX", "40": "UART_RX",
               "23": "USB_DM", "24": "USB_DP",
               "11": "SD_SCK", "12": "SD_MISO", "13": "SD_MOSI", "25": "SD_CS",
               "14": "CAM_XCLK", "36": "CAM_SIOD", "35": "CAM_SIOC",
               "19": "CAM_Y2", "21": "CAM_Y3", "22": "CAM_Y4", "20": "CAM_Y5",
               "18": "CAM_Y6", "16": "CAM_Y7", "15": "CAM_Y8", "30": "CAM_Y9",
               "34": "CAM_VSYNC", "27": "CAM_HREF", "17": "CAM_PCLK",
               **{str(n): "GND" for n in
                  [1, 2, 42, 43, 46, 47, 48, 49, 50, 51, 52, 53, 54, 55, 56,
                   57, 58, 59, 60, 61, 62, 63, 64, 65]}})
    ctx.rcl("C", "100n", (296, 40), "+3V3", "GND")
    ctx.rcl("C", "10u", (304, 40), "+3V3", "GND",
            fp="Capacitor_SMD:C_0805_2012Metric")

def add_mcu_bare(sch, ctx):
    sch.text("MCU — bare ESP32-S3R8 + flash + xtal + RF", (235, 22), 1.7)
    sch.place("U1", "MCU_Espressif", "ESP32-S3", "ESP32-S3R8",
              "Package_DFN_QFN:QFN-56-1EP_7x7mm_P0.4mm_EP4.15x4.15mm",
              (270, 75),
              {"1": "RF_FEED", "4": "EN",
               "2": "+3V3", "3": "+3V3", "20": "+3V3", "46": "+3V3",
               "55": "+3V3", "56": "+3V3", "29": "VDD_SPI", "57": "GND",
               "5": "IO0", "6": "STATUS_LED",
               "49": "UART_TX", "50": "UART_RX",
               "25": "USB_DM", "26": "USB_DP",
               "12": "SD_SCK", "13": "SD_MISO", "14": "SD_MOSI", "27": "SD_CS",
               "15": "CAM_XCLK", "45": "CAM_SIOD", "44": "CAM_SIOC",
               "21": "CAM_Y2", "23": "CAM_Y3", "24": "CAM_Y4", "22": "CAM_Y5",
               "19": "CAM_Y6", "17": "CAM_Y7", "16": "CAM_Y8", "36": "CAM_Y9",
               "43": "CAM_VSYNC", "37": "CAM_HREF", "18": "CAM_PCLK",
               "30": "FLASH_HD", "31": "FLASH_WP", "32": "FLASH_CS",
               "33": "FLASH_CLK", "34": "FLASH_Q", "35": "FLASH_D",
               "53": "XTAL_N", "54": "XTAL_P"})
    sch.place("U2", "Memory_Flash", "W25Q32JVSS", "W25Q64JVSSIQ",
              "Package_SO:SOIC-8_3.9x4.9mm_P1.27mm", (320, 45),
              {"1": "FLASH_CS", "6": "FLASH_CLK", "5": "FLASH_D",
               "2": "FLASH_Q", "3": "FLASH_WP", "7": "FLASH_HD",
               "8": "VDD_SPI", "4": "GND"})
    ctx.rcl("C", "1u", (338, 38), "VDD_SPI", "GND")
    sch.place("Y1", "Device", "Crystal_GND24", "40MHz",
              "Crystal:Crystal_SMD_3225-4Pin_3.2x2.5mm", (320, 80),
              {"1": "XTAL_P", "3": "XTAL_N", "2": "GND", "4": "GND"})
    ctx.rcl("C", "12p", (332, 74), "XTAL_P", "GND")
    ctx.rcl("C", "12p", (340, 74), "XTAL_N", "GND")
    # RF pi match + antenna
    sch.text("RF: 50R trace, pi-match, antenna keepout", (300, 105), 1.7)
    ctx.rcl("C", "DNP", (310, 115), "RF_FEED", "GND")
    ctx.rcl("L", "0R-placeholder", (318, 115), "RF_FEED", "ANT_FEED",
            fp="Inductor_SMD:L_0402_1005Metric")
    ctx.rcl("C", "DNP", (326, 115), "ANT_FEED", "GND")
    sch.place("ANT1", "Device", "Antenna_Chip", "2450AT18B100",
              "RF_Antenna:Johanson_2450AT18x100", (340, 115),
              {"1": "ANT_FEED"})
    # decoupling farm
    for i, v in enumerate(["100n", "100n", "100n", "1u", "10u"]):
        ctx.rcl("C", v, (250 + i * 12, 122), "+3V3", "GND",
                fp="Capacitor_SMD:C_0805_2012Metric" if v == "10u" else None)

def add_mcu_pico(sch, ctx):
    # ESP32-S3-PICO-1 SiP: same S3 die, but flash + PSRAM + 40MHz crystal are
    # bonded INSIDE the package, so the SPI-flash pads (30-35) and XTAL pads
    # (53,54) are NC externally. Reuse the bare-S3 symbol; drop the external
    # flash chip and crystal that add_mcu_bare needed. Pin numbers are 1:1 with
    # the PICO-1 LGA-56 pad map (datasheet v1.2). Antenna is still external.
    sch.text("MCU — ESP32-S3-PICO-1 SiP (flash+PSRAM+xtal in-package)",
             (235, 22), 1.7)
    sch.text("footprint: add Espressif LGA-56 land pattern before layout",
             (235, 26), 1.5)
    sch.place("U1", "MCU_Espressif", "ESP32-S3", "ESP32-S3-PICO-1-N8R8",
              "Espressif:ESP32-S3-PICO-1",  # add land pattern in KiCad
              (270, 75),
              {"1": "RF_FEED", "4": "EN",
               "2": "+3V3", "3": "+3V3", "20": "+3V3", "46": "+3V3",
               "55": "+3V3", "56": "+3V3", "29": "VDD_SPI", "57": "GND",
               "5": "IO0", "6": "STATUS_LED",
               "49": "UART_TX", "50": "UART_RX",
               "25": "USB_DM", "26": "USB_DP",
               "12": "SD_SCK", "13": "SD_MISO", "14": "SD_MOSI", "27": "SD_CS",
               "15": "CAM_XCLK", "45": "CAM_SIOD", "44": "CAM_SIOC",
               "21": "CAM_Y2", "23": "CAM_Y3", "24": "CAM_Y4", "22": "CAM_Y5",
               "19": "CAM_Y6", "17": "CAM_Y7", "16": "CAM_Y8", "36": "CAM_Y9",
               "43": "CAM_VSYNC", "37": "CAM_HREF", "18": "CAM_PCLK"})
    # pads 30-35 (int. flash), 53-54 (int. xtal) intentionally left NC
    ctx.rcl("C", "1u", (300, 40), "VDD_SPI", "GND")
    # RF pi match + antenna (external, same as bare)
    sch.text("RF: 50R trace, pi-match, antenna keepout", (300, 105), 1.7)
    ctx.rcl("C", "DNP", (310, 115), "RF_FEED", "GND")
    ctx.rcl("L", "0R-placeholder", (318, 115), "RF_FEED", "ANT_FEED",
            fp="Inductor_SMD:L_0402_1005Metric")
    ctx.rcl("C", "DNP", (326, 115), "ANT_FEED", "GND")
    sch.place("ANT1", "Device", "Antenna_Chip", "2450AT18B100",
              "RF_Antenna:Johanson_2450AT18x100", (340, 115),
              {"1": "ANT_FEED"})
    for i, v in enumerate(["100n", "100n", "1u", "10u"]):
        ctx.rcl("C", v, (250 + i * 12, 122), "+3V3", "GND",
                fp="Capacitor_SMD:C_0805_2012Metric" if v == "10u" else None)

def add_mcu_c3(sch, ctx):
    # ESP32-C3-MINI-1: pre-certified module — PCB antenna + 4MB flash inside.
    # No external RF, flash, crystal, PSRAM. Chat-only lite board.
    sch.text("MCU — ESP32-C3-MINI-1 (module: antenna+flash integrated)",
             (235, 22), 1.7)
    c3gnd = {str(n): "GND" for n in
             [1, 2, 11, 14, 36, 37, 38, 39, 40, 41, 42, 43, 44, 45, 46, 47,
              48, 49, 50, 51, 52, 53]}
    sch.place("U1", "nlink_parts", "ESP32-C3-MINI-1", "ESP32-C3-MINI-1-N4",
              "Espressif:ESP32-C3-MINI-1", (270, 70),
              {"3": "+3V3", "8": "EN", "12": "IO0", "22": "STATUS_LED",
               "21": "UART_TX", "20": "UART_RX",   # GPIO7 tx, GPIO6 rx
               "26": "USB_DM", "27": "USB_DP",      # GPIO18/19 native USB
               **c3gnd})
    ctx.rcl("C", "100n", (300, 40), "+3V3", "GND")
    ctx.rcl("C", "10u", (308, 40), "+3V3", "GND",
            fp="Capacitor_SMD:C_0805_2012Metric")

# ---------------------------------------------------------------------------
# board stub with outline
# ---------------------------------------------------------------------------
def write_pcb(path, w, h):
    if os.path.exists(path):
        print(f"  (kept existing {path} - not overwriting board work)")
        return
    open(path, "w").write(f"""(kicad_pcb (version 20221018) (generator nlink_gen)
  (general (thickness 1.0))
  (paper "A4")
  (layers
    (0 "F.Cu" signal) (1 "In1.Cu" signal) (2 "In2.Cu" signal)
    (31 "B.Cu" signal) (36 "B.SilkS" user) (37 "F.SilkS" user)
    (38 "B.Mask" user) (39 "F.Mask" user)
    (44 "Edge.Cuts" user) (40 "Dwgs.User" user)
  )
  (setup (pad_to_mask_clearance 0))
  (gr_rect (start 50 50) (end {50 + w} {50 + h})
    (stroke (width 0.1) (type default)) (layer "Edge.Cuts") (tstamp {U()}))
  (gr_text "nternet-Link {w}x{h}mm outline" (at {50 + w / 2} {48}) (layer "Dwgs.User")
    (tstamp {U()}) (effects (font (size 1.5 1.5) (thickness 0.3))))
)
""")

def write_pro(path, name):
    json.dump({"meta": {"filename": f"{name}.kicad_pro", "version": 1},
               "boards": [], "libraries": {"pinned_footprint_libs": [],
               "pinned_symbol_libs": []}, "sheets": []},
              open(path, "w"), indent=2)

# ---------------------------------------------------------------------------
# name, title, mcu-fn, has camera+sd?, board (w,h)
MODELS = {
    "mini": ("nlink-proto", "ESP32-S3-MINI-1 prototype (~60x16mm)",
             "add_mcu_mini", True, (60, 16)),
    "bare": ("nlink-stick", "bare ESP32-S3R8 stick (<=60x12.5mm)",
             "add_mcu_bare", True, (60, 12.5)),
    "cam":  ("nlink-cam", "ESP32-S3-PICO-1 camera stick (<=60x12.5mm)",
             "add_mcu_pico", True, (60, 12.5)),
    "lite": ("nlink-lite", "ESP32-C3-MINI-1 chat-only stealth",
             "add_mcu_c3", False, (34, 15)),
}

def build(variant):
    name, title, mcu_fn, full, board = MODELS[variant]
    d = os.path.join(OUT, name)
    os.makedirs(d, exist_ok=True)
    sch = Schematic(name)
    ctx = Ctx(sch)
    sch.text(f"nternet-Link V4 · {name} — {title} · generated, netlist-verified"
             " — tidy placement freely, nets live in the labels", (30, 12), 2.5)
    add_shared(sch, ctx)            # calc plug + ESD + bridge + 3V3 buck
    if full:
        add_camera_sd(sch, ctx)     # OV5640 FPC + microSD
    # lite uses hole-free SMD pogo pads (TC2030 drills can't clear a board this small)
    j4_fp = ("Connector_PinHeader_1.27mm:PinHeader_2x03_P1.27mm_Vertical_SMD"
             if variant == "lite" else
             "Connector:Tag-Connect_TC2030-IDC-FP_2x03_P1.27mm_Vertical")
    add_program(sch, ctx, j4_fp)    # prog pads + straps + LED
    globals()[mcu_fn](sch, ctx)     # MCU section
    sch.write(os.path.join(d, f"{name}.kicad_sch"))
    write_pro(os.path.join(d, f"{name}.kicad_pro"), name)
    write_pcb(os.path.join(d, f"{name}.kicad_pcb"), *board)
    print(f"wrote {name}")
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

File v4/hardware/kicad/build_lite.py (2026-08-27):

#!/usr/bin/env python3
"""nlink-lite: compact 40x15mm stick, clean placement, ready for full routing.

Layout (left -> right): mini-USB plug pads | power switch + ESD | CP2102N
bridge | buck cluster | passives rows | ESP32-C3-MINI-1 with antenna at the
right board edge. TC2030 programming pads + strap pulls live on the BACK
(flipped by finish_lite.py, which also verifies hole/pad conflicts).

Coordinates chosen against measured courtyards; finish_lite.py verifies:
courtyard overlaps, NPTH-through-hole vs front pads, outline containment.
"""
import os, uuid, importlib.util

HERE = os.path.dirname(os.path.abspath(__file__))
spec = importlib.util.spec_from_file_location("bb", os.path.join(HERE, "build_board.py"))
bb = importlib.util.module_from_spec(spec); spec.loader.exec_module(bb)

FP_DIRS = ["/usr/share/kicad/footprints", os.path.join(HERE, "lib")]
def load_fp(lib, name):
    for d in FP_DIRS:
        p = f"{d}/{lib}.pretty/{name}.kicad_mod"
        if os.path.exists(p): return open(p).read()
    raise FileNotFoundError(f"{lib}:{name}")
bb.load_footprint = load_fp

def U(): return str(uuid.uuid4())

# Board: x 50..90, y 50..65 (40 x 15 mm). Antenna zone: x > ANT_CLIP.
BOARD = (50, 50, 90, 65)
ANT_CLIP = 83.4      # GND pours stop here (module antenna keepout)

C3_GND = {str(n): "GND" for n in
          [1, 2, 11, 14, 36, 37, 38, 39, 40, 41, 42, 43, 44, 45, 46, 47, 48,
           49, 50, 51, 52, 53]}

# BACK_SET refs get flipped to B.Cu by finish_lite.py
BACK_SET = ["J4", "R4", "C6", "R5"]

PARTS = [
    # calculator plug (through-hole pads for the mini-B pigtail)
    ("J1", "USB_MiniB_PLUG_to_calc", "Connector_PinHeader_2.54mm",
     "PinHeader_1x05_P2.54mm_Vertical", (52, 62.6), 180,
     {"1": "VBUS_IN", "2": "CALC_DM", "3": "CALC_DP", "5": "GND"}),
    # power switch on the top edge, actuator outward
    ("SW1", "PWR_SW", "Button_Switch_SMD", "SW_SPDT_PCM12", (58.6, 62.0), 180,
     {"1": "VBUS", "2": "VBUS_IN"}),
    # ESD straight in the USB path between plug and bridge
    ("U5", "USBLC6-2SC6", "Package_TO_SOT_SMD", "SOT-23-6", (56.5, 57.2), 0,
     {"1": "CALC_DM", "6": "CALC_DM", "3": "CALC_DP", "4": "CALC_DP",
      "5": "VBUS", "2": "GND"}),
    ("U3", "CP2102N-A02-GQFN24", "Package_DFN_QFN",
     "QFN-24-1EP_4x4mm_P0.5mm_EP2.6x2.6mm", (62.5, 57.5), 0,
     {"3": "CALC_DP", "4": "CALC_DM", "8": "VBUS", "5": "+3V3", "6": "+3V3",
      "7": "+3V3", "9": "CP_RSTn", "20": "UART_TX", "21": "UART_RX",
      "2": "GND", "25": "GND"}),
    # aligned top passive row (y = 52.3)
    ("R1", "10k", "Resistor_SMD", "R_0402_1005Metric", (64.5, 52.3), 0,
     {"1": "+3V3", "2": "CP_RSTn"}),
    ("C1", "100n", "Capacitor_SMD", "C_0402_1005Metric", (66.5, 52.3), 0,
     {"1": "+3V3", "2": "GND"}),
    ("C2", "4.7u", "Capacitor_SMD", "C_0402_1005Metric", (68.5, 52.3), 0,
     {"1": "+3V3", "2": "GND"}),
    ("R6", "470", "Resistor_SMD", "R_0402_1005Metric", (70.5, 52.3), 0,
     {"1": "STATUS_LED", "2": "LED_A"}),
    ("D1", "LED_STATUS", "LED_SMD", "LED_0402_1005Metric", (70.8, 54.0), 0,
     {"1": "GND", "2": "LED_A"}),
    # buck cluster, bottom band
    ("C3", "10u", "Capacitor_SMD", "C_0805_2012Metric", (63.5, 62.4), 90,
     {"1": "VBUS", "2": "GND"}),
    ("U4", "TLV62569DBV", "Package_TO_SOT_SMD", "SOT-23-5", (66.7, 62.4), 0,
     {"4": "VBUS", "1": "VBUS", "2": "GND", "3": "SW_NODE", "5": "FB_3V3"}),
    ("L1", "2.2uH", "Inductor_SMD", "L_1210_3225Metric", (70.0, 62.3), 90,
     {"1": "SW_NODE", "2": "+3V3"}),
    ("R2", "453k", "Resistor_SMD", "R_0402_1005Metric", (66.2, 59.3), 0,
     {"1": "+3V3", "2": "FB_3V3"}),
    ("R3", "100k", "Resistor_SMD", "R_0402_1005Metric", (67.8, 59.3), 0,
     {"1": "FB_3V3", "2": "GND"}),
    ("C4", "22u", "Capacitor_SMD", "C_0805_2012Metric", (70.5, 58.6), 90,
     {"1": "+3V3", "2": "GND"}),
    ("C5", "10u", "Capacitor_SMD", "C_0805_2012Metric", (70.8, 55.9), 90,
     {"1": "+3V3", "2": "GND"}),
    # module: rot set so antenna points +x; finish_lite.py verifies direction
    ("U1", "ESP32-C3-MINI-1-N4", "Espressif", "ESP32-C3-MINI-1", (80.8, 57.4), 90,
     {"3": "+3V3", "8": "EN", "12": "IO0", "22": "STATUS_LED",
      "21": "UART_TX", "20": "UART_RX", "26": "USB_DM", "27": "USB_DP",
      **C3_GND}),
    # back-side set (flipped by finish_lite.py)
    ("J4", "PROG_PADS_2x3_POGO", "Connector_PinHeader_1.27mm",
     "PinHeader_2x03_P1.27mm_Vertical_SMD", (76.5, 57.5), 0,
     {"1": "+3V3", "2": "GND", "3": "EN", "4": "IO0",
      "5": "USB_DM", "6": "USB_DP"}),
    ("R4", "10k", "Resistor_SMD", "R_0402_1005Metric", (74, 53.5), 0,
     {"1": "+3V3", "2": "EN"}),
    ("C6", "100n", "Capacitor_SMD", "C_0402_1005Metric", (76, 53.5), 0,
     {"1": "EN", "2": "GND"}),
    ("R5", "10k", "Resistor_SMD", "R_0402_1005Metric", (78, 53.5), 0,
     {"1": "+3V3", "2": "IO0"}),
]

def build(out=None):
    netnames = []
    for *_, nets in PARTS:
        for n in nets.values():
            if n and n not in netnames: netnames.append(n)
    codes = {n: i + 1 for i, n in enumerate(sorted(netnames))}
    fps = [bb.instantiate(r, v, lib, fp, at, rot, nets, codes)
           for r, v, lib, fp, at, rot, nets in PARTS]
    nets_sx = "\n".join(f'  (net {c} "{n}")' for n, c in sorted(codes.items(), key=lambda kv: kv[1]))
    x0, y0, x1, y1 = BOARD
    outline = (f'  (gr_rect (start {x0} {y0}) (end {x1} {y1})'
               f' (stroke (width 0.1) (type default)) (layer "Edge.Cuts") (tstamp {U()}))')
    texts = "\n".join([
        f'  (gr_text "nlink-lite" (at 57 66.8) (layer "F.SilkS") (tstamp {U()})'
        f' (effects (font (size 1 1) (thickness 0.15))))',
        f'  (gr_text "ANTENNA" (at 87 48.9) (layer "Dwgs.User") (tstamp {U()})'
        f' (effects (font (size 0.9 0.9) (thickness 0.14))))'])
    board = f"""(kicad_pcb (version 20221018) (generator nlink_gen)
  (general (thickness 1.0))
  (paper "A4")
  (layers
    (0 "F.Cu" signal) (1 "In1.Cu" signal) (2 "In2.Cu" signal) (31 "B.Cu" signal)
    (34 "B.Paste" user) (35 "F.Paste" user)
    (36 "B.SilkS" user "B.Silkscreen") (37 "F.SilkS" user "F.Silkscreen")
    (38 "B.Mask" user) (39 "F.Mask" user)
    (40 "Dwgs.User" user "User.Drawings") (44 "Edge.Cuts" user)
    (46 "B.CrtYd" user "B.Courtyard") (47 "F.CrtYd" user "F.Courtyard")
    (48 "B.Fab" user) (49 "F.Fab" user)
  )
  (setup (pad_to_mask_clearance 0))
  (net 0 "")
{nets_sx}

{outline}
{texts}

{chr(10).join(fps)}
)
"""
    out = out or os.path.join(HERE, "nlink-lite", "nlink-lite.kicad_pcb")
    open(out, "w").write(board)
    print(f"wrote {out}: {len(PARTS)} footprints, {len(netnames)} nets")

if __name__ == "__main__":
    build()

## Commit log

2026-08-15 Add V3 proxy server and expand camera firmware and Nspire client
    - V3/server: local HTTP proxy (FastAPI-style), launchd plists for the
    proxy and mDNS responder, plus install/uninstall scripts
    - esp32_camera.ino: runtime WiFi provisioning over serial, additional
    SCAN/RESETWIFI commands
    - nspire_ai_camera.lua: expanded on-calculator client UI and flow
    - Ship the built nspire_ai_camera.tns
    - Ignore .DS_Store and scratch .tns builds
    [esp32_camera.ino]
2026-08-25 Full Overhaul
    [nlink-cam.kicad_pcb, nlink-cam.kicad_sch, nlink-lite.kicad_pcb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]
2026-08-27 Updated v4 pcb
    [nlink-cam.kicad_pcb, nlink-cam.kicad_sch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]
